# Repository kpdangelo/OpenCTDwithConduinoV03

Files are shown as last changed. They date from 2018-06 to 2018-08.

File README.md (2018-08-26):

# OpenCTDwithConduinoV03

This has drift issues, see https://github.com/kpdangelo/OpenCTD-Conduino-K1.0

This is version 3 of my conduino implementation
The circuit more closely follows the Analog Devices app note, CN-0217, in an attempt to mitigate the drift I was seeing in the Conduino reading with versions 1 and 2.
Namely, the AC coupling capacitors in series with the USB electrodes were taken studied, and a SPDT analog mux was added to swap the electrodes for each measurement in an attempt to see if there was biasing going on of the electrodes.
All fairly inconclusive at this time.

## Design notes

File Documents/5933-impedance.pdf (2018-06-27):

AD5933 Output Impedance

AC coupling at the VOUT output of the AD5933 creates signal attenuation due to the RO/R1/C1 pole and C1/R1 zero. Where RO is the 600Ω output impedance when the AD5933 is configured in output Range 4.

With 1uF and 1.6kΩ C1/R1 combination, the 100 kHz signal is attenuated by approximately 2.8dB.

Changing to the recommended values of 47nF and 25kΩ from the AD5933 datasheet results in a much lower attenuation of approximately 0.2dB.

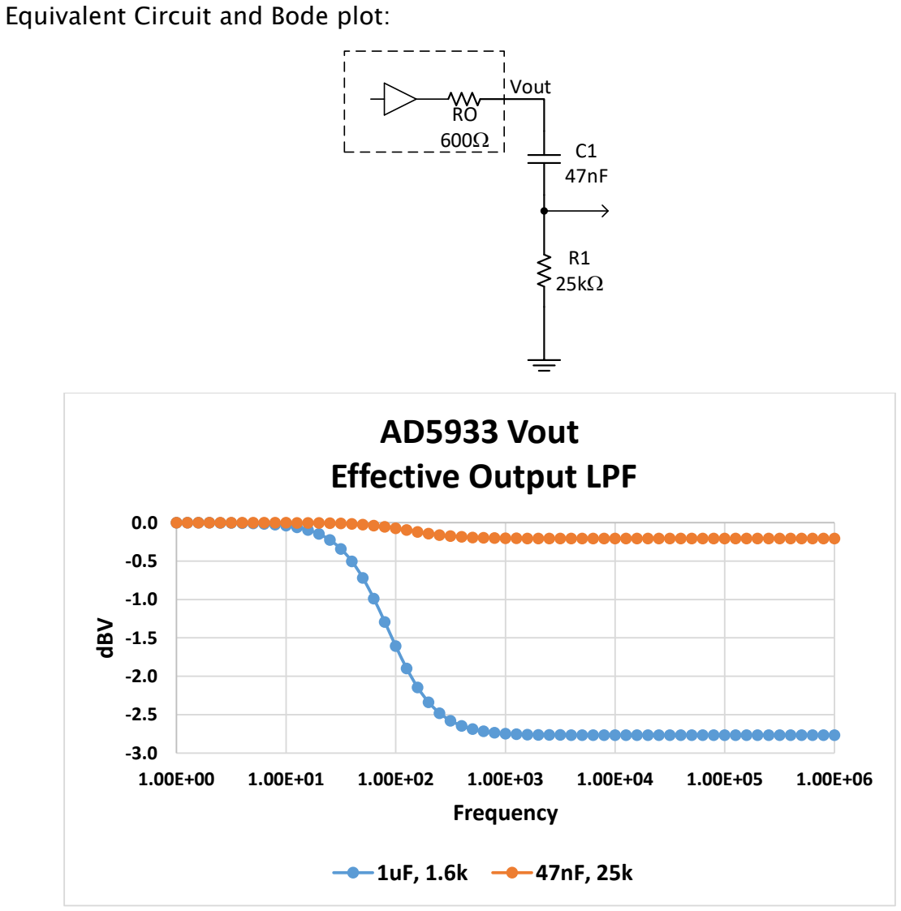
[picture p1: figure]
Equivalent Circuit and Bode plot:; Vout; dBV; Frequency; AD5933 Vout Effective Output LPF

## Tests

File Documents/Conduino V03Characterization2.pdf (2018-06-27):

Conduino V03 Characterization

1. Using a reference 180 ohm resistor

Using an 0603 resistor soldered to the end of a 9” USB cable. The resistor is a Panasonic ERA-3AEB181V, 0.1% 180 Ohm, with a 25 ppm temp-co.

Pretty stable, has 0.08% noise in the reading. Something happened at about 5 ½ hours, maybe the watch-dog timer was triggered. There is a 0.35% transient in the reading there. Notice that the temperature also had a transient at the same time, so something odd happened.

At 10 minute startup, the reading is 0.04% below where it ends up hours later.

Temperature has no measurable effect since the resistor temp-co is so small.

Compared to the USB probe, this looks pretty stable.

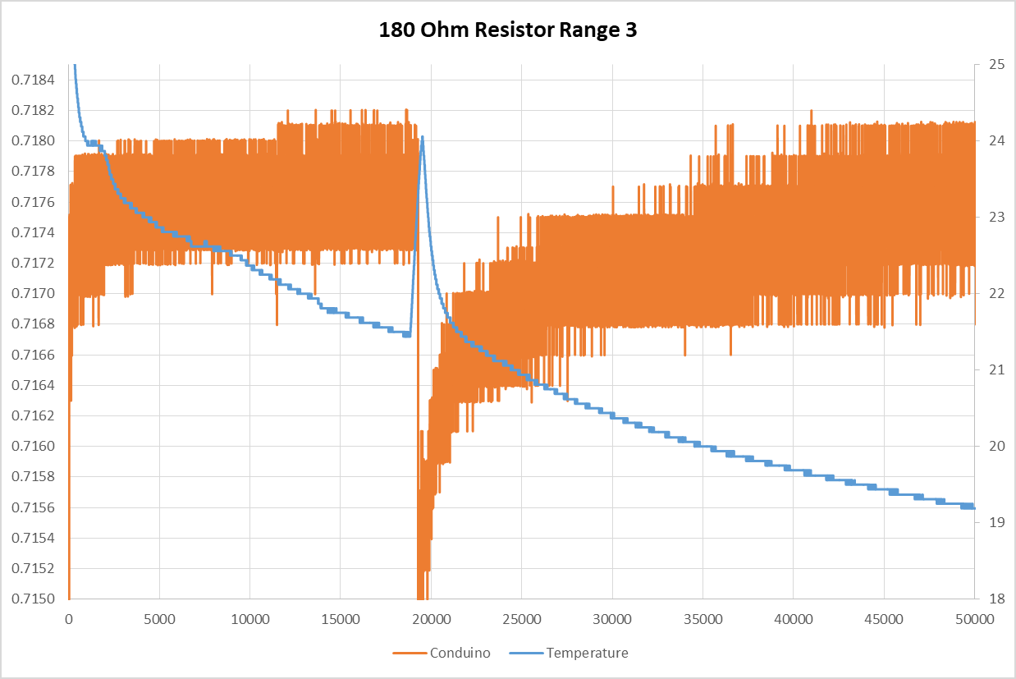
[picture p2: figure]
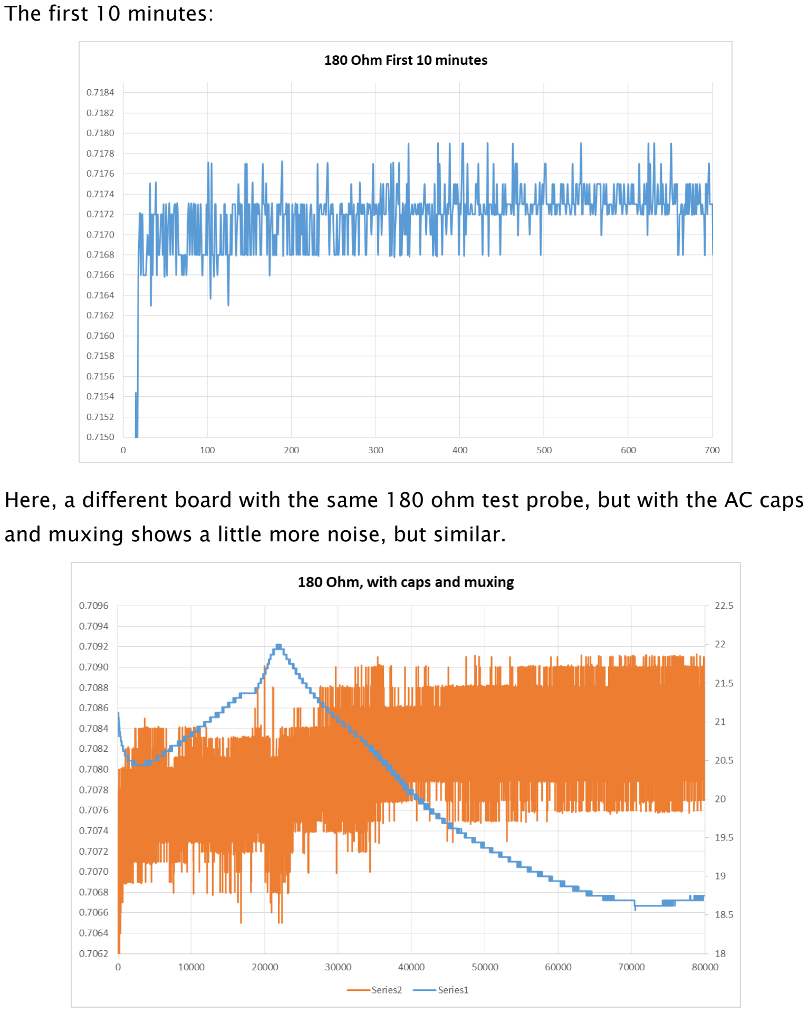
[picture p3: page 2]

The first 10 minutes:

Here, a different board with the same 180 ohm test probe, but with the AC caps and muxing shows a little more noise, but similar.

2. Tests using a USB probe in ~35ppt saline solution with a recirculation pump. The AC caps are C1 and C4 that are in series with the D+ and Delectrodes of the USB probe. The mux is a 2-channel SPDT analog switch. It is used to swap the USB probe electrodes each time a measurement is taken.
AC Caps | Mux | Notes
No | No | So-so tracking, strong startup drift
No | Yes | Similar
Yes | Yes | So-so tracking, strong startup drift
Yes | No | Really bad tracking and startup drift

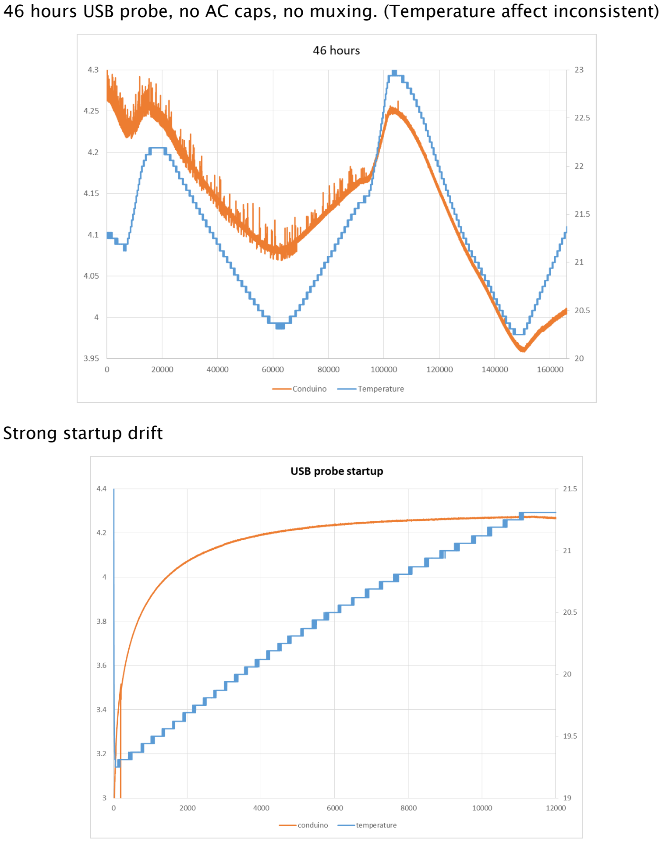
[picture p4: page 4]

46 hours USB probe, no AC caps, no muxing. (Temperature affect inconsistent)

Strong startup drift

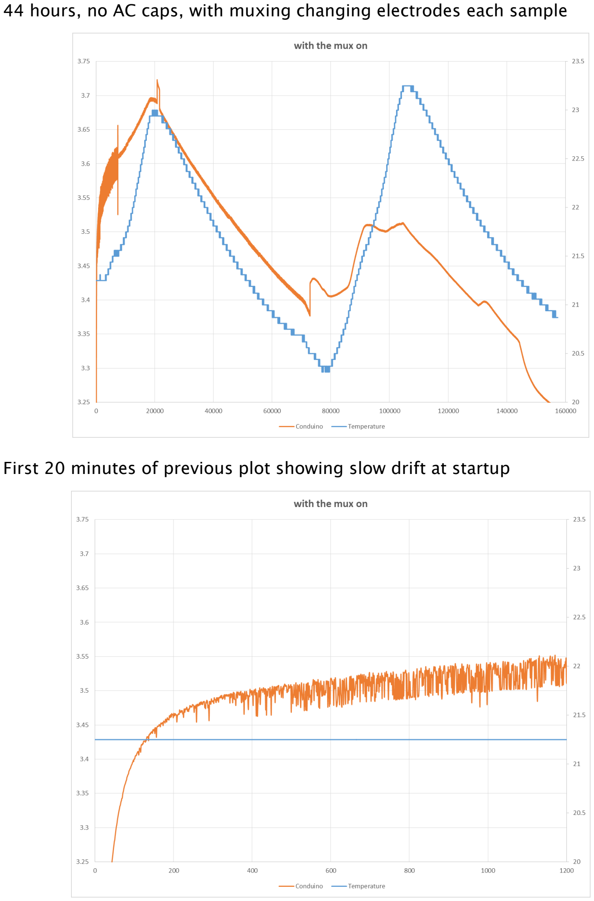
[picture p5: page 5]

44 hours, no AC caps, with muxing changing electrodes each sample

First 20 minutes of previous plot showing slow drift at startup

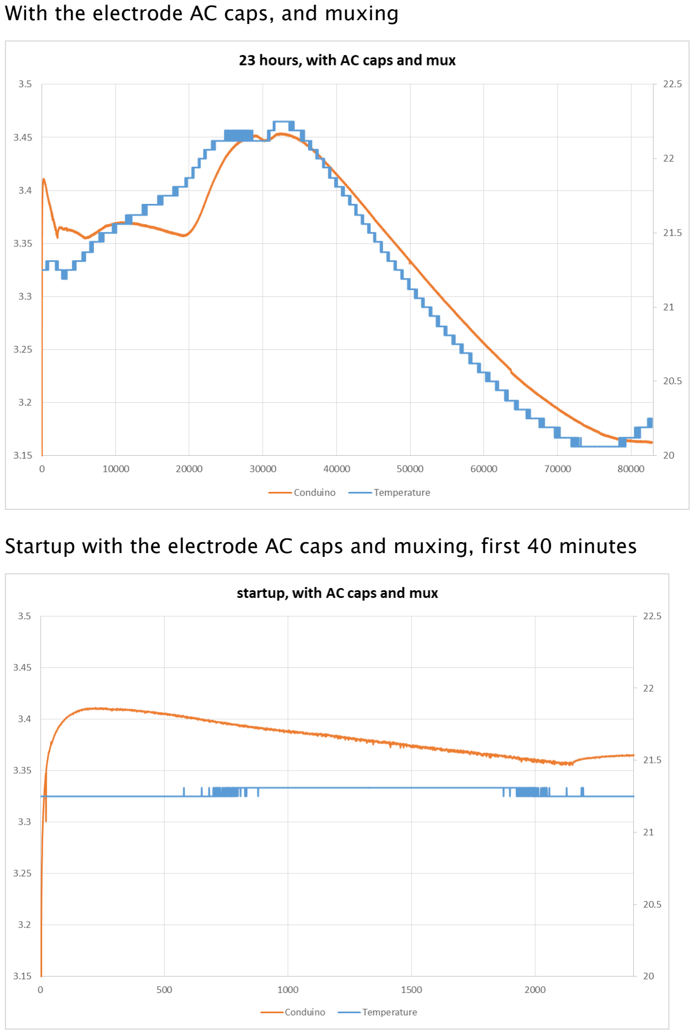
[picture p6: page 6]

With the electrode AC caps, and muxing

Startup with the electrode AC caps and muxing, first 40 minutes

With AC caps but no mux, shows strong drift unrelated to temperature

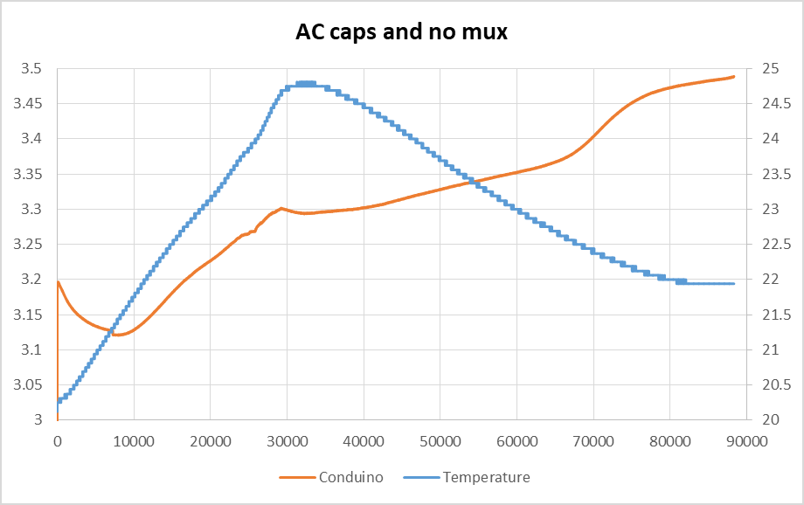
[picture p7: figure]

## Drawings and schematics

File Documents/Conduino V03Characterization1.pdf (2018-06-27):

Conduino V03 Characterization

V03 uses a low noise LDO (LP5907) to create a local 3.3v supply for the Conduino analog circuitry. Resistor dividers are used to bias the amplifiers (per Analog Devices app note CN-0217). Series AC capacitors are shorted. LDO is cycled on and off for each measurement once a second.

V03 also has a low input offset (65uV) amplifier (ADA8606) with plenty of bandwidth (10 MHz).

Result of long soak, measurement following temperature (decent?):

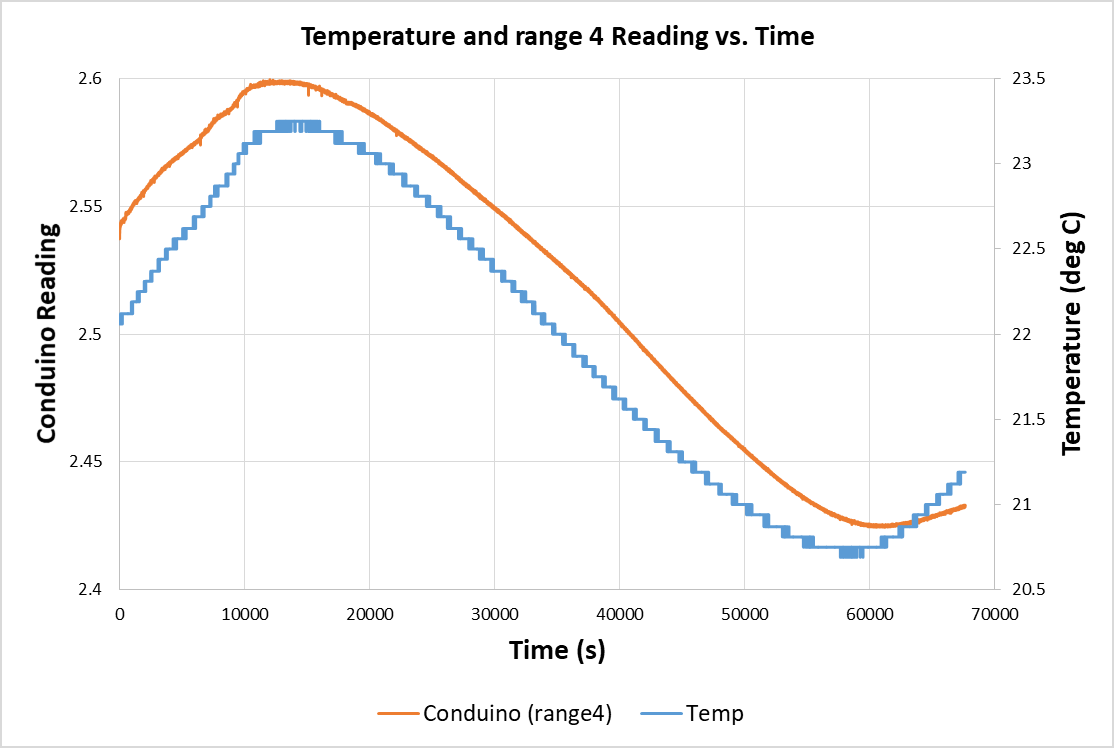
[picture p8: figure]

At the end of this run, the USB probes broke off.

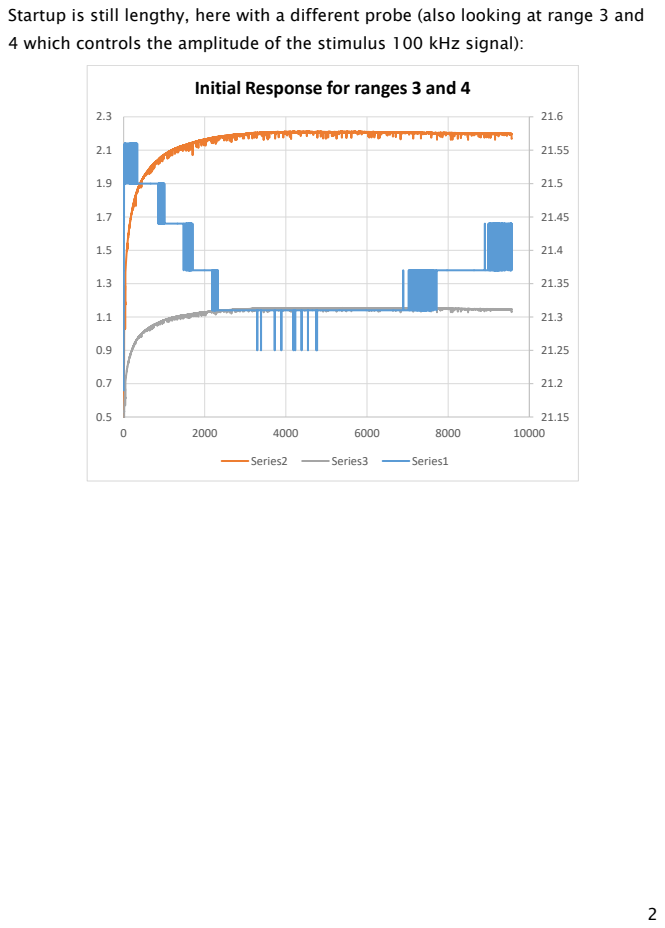
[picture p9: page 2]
Series2; Series3; Series1

Startup is still lengthy, here with a different probe (also looking at range 3 and
4 which controls the amplitude of the stimulus 100 kHz signal):

Initial Response for ranges 3 and 4

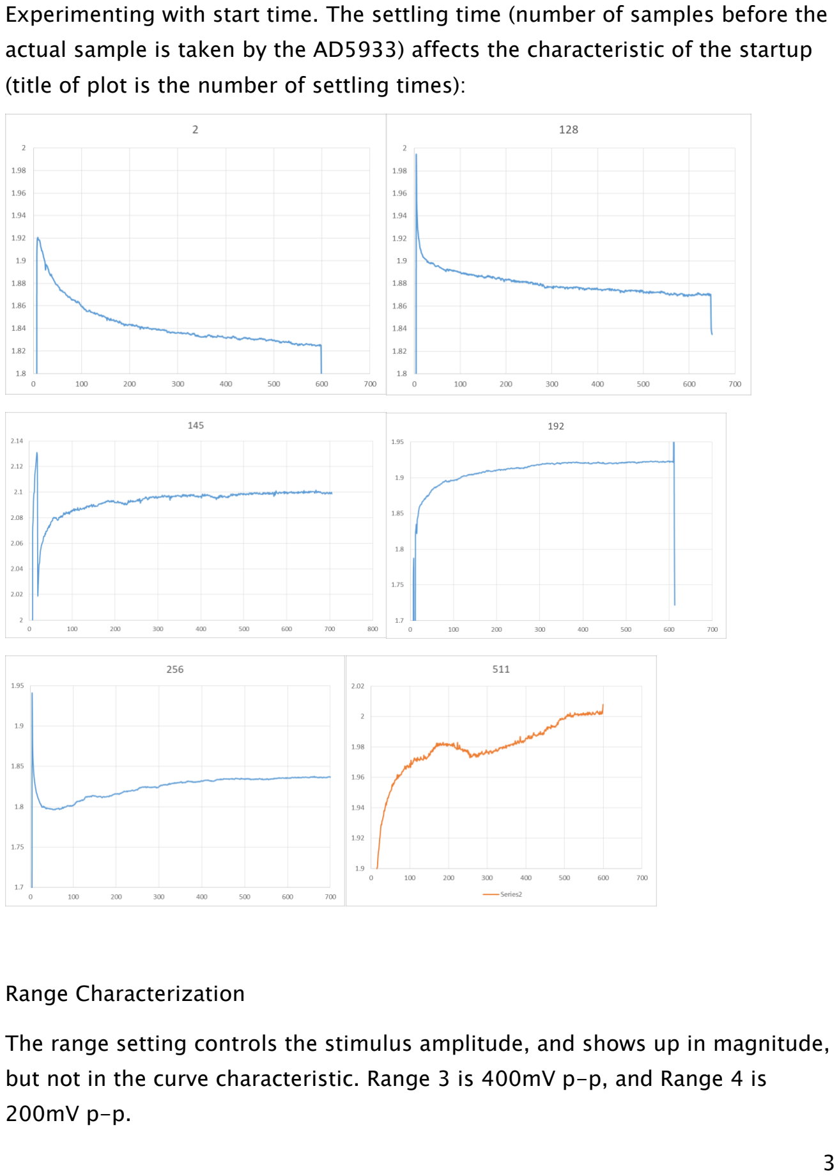
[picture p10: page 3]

Experimenting with start time. The settling time (number of samples before the actual sample is taken by the AD5933) affects the characteristic of the startup (title of plot is the number of settling times):

Range Characterization

The range setting controls the stimulus amplitude, and shows up in magnitude, but not in the curve characteristic. Range 3 is 400mV p-p, and Range 4 is 200mV p-p.

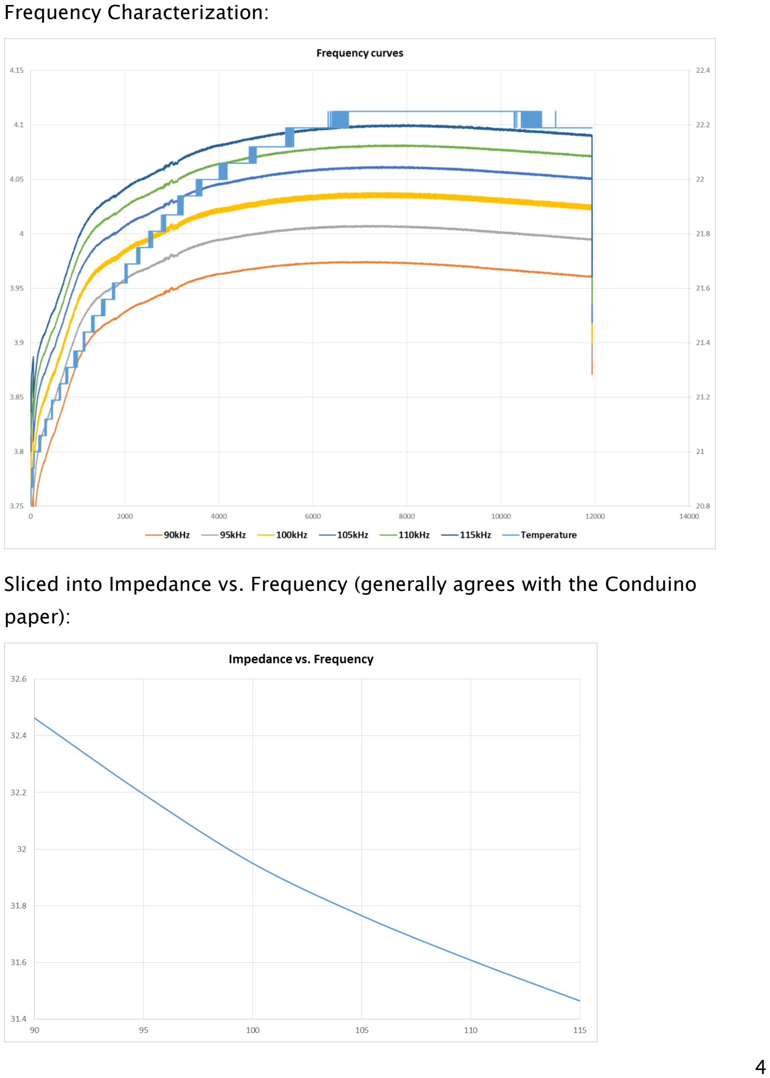
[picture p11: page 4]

Frequency Characterization:

Sliced into Impedance vs. Frequency (generally agrees with the Conduino paper):

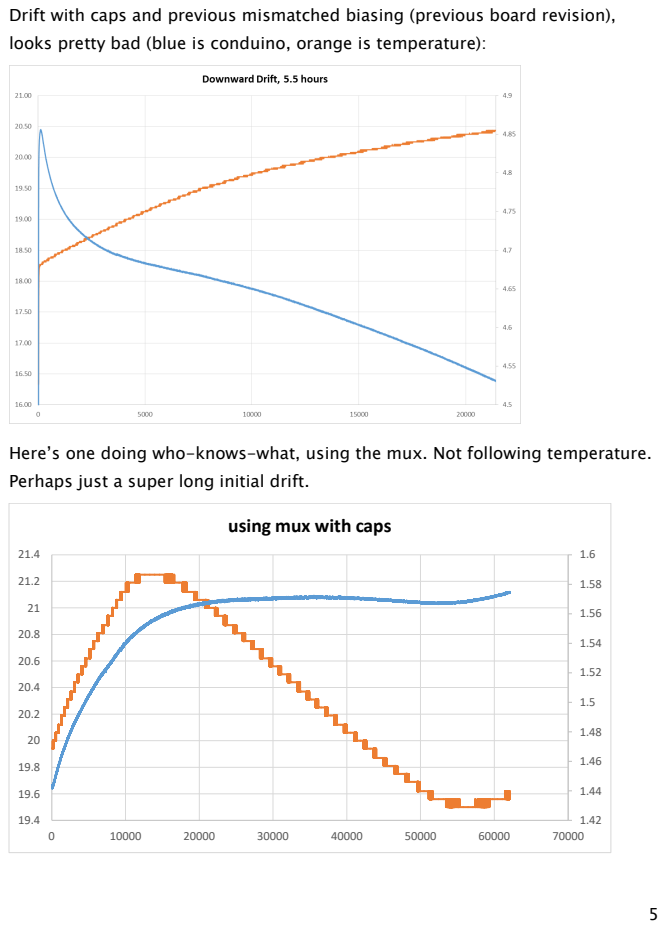
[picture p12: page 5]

Drift with caps and previous mismatched biasing (previous board revision),
looks pretty bad (blue is conduino, orange is temperature):

Here’s one doing who-knows-what, using the mux. Not following temperature.
Perhaps just a super long initial drift.

using mux with caps

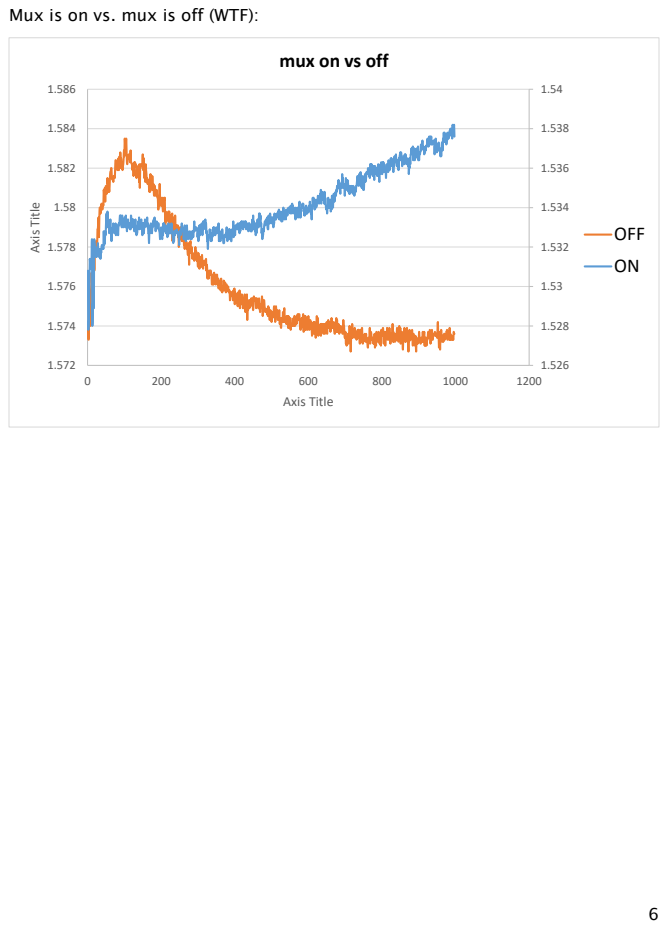
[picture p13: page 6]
Axis Title; OFF

Mux is on vs. mux is off (WTF):

mux on vs off

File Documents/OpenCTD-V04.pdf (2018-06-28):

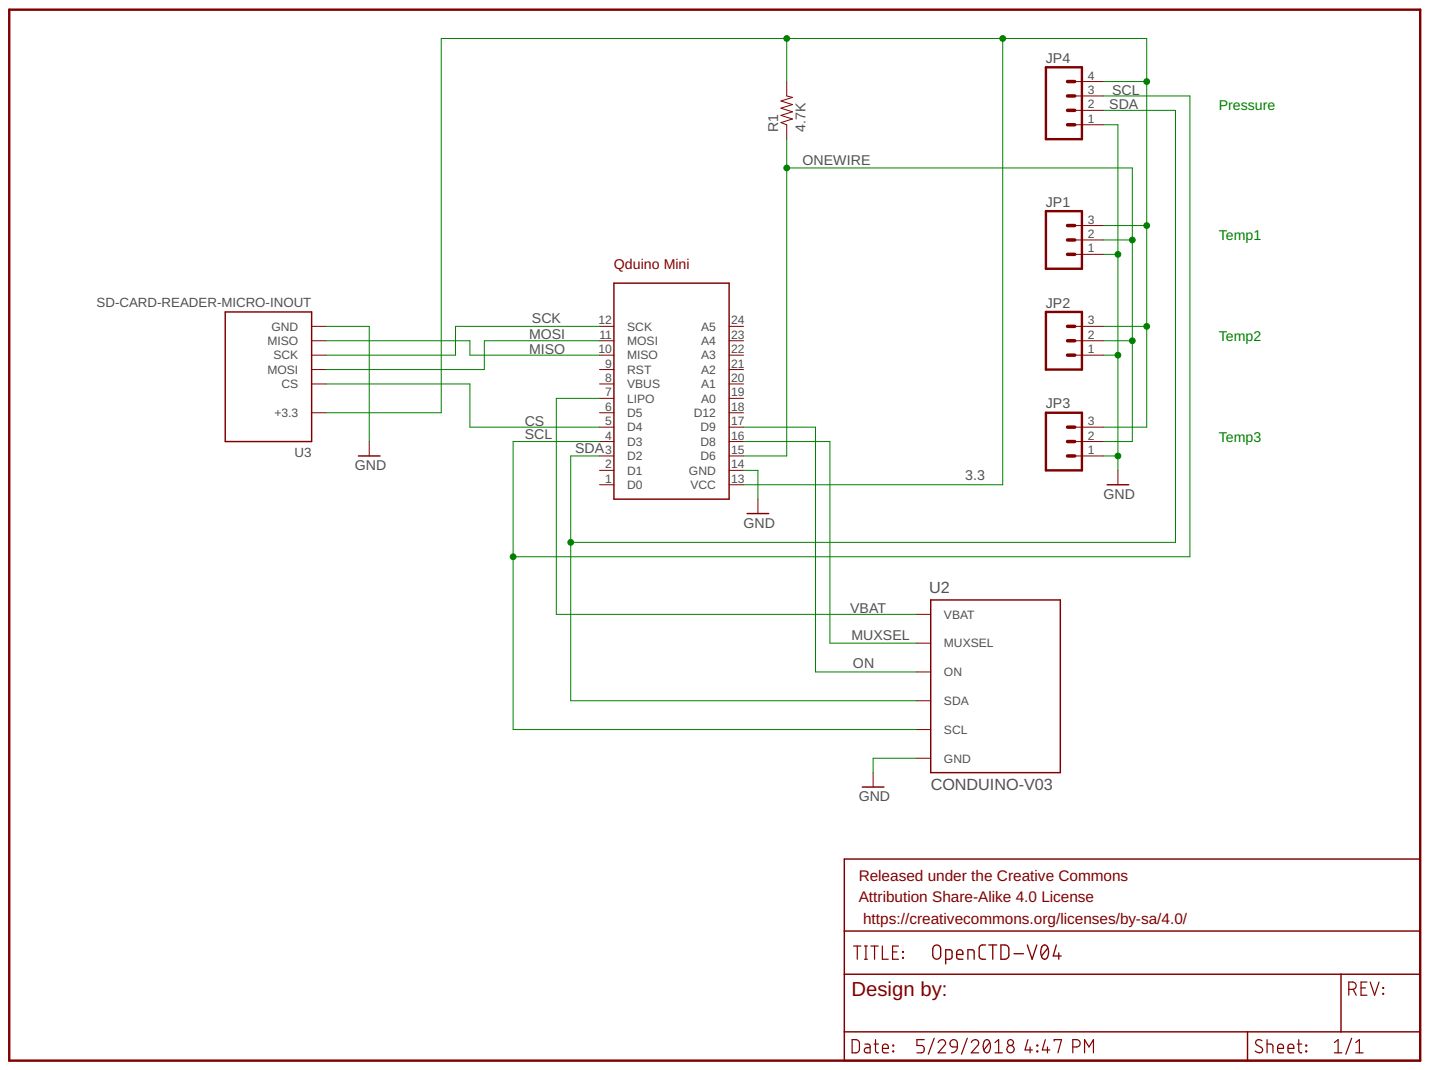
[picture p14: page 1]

2 SDA

SD-CARD-READER-MICRO-INOUT

SCL SDA ONMUXSEL VBAT

Released under the Creative Commons Attribution Share-Alike 4.0 License

https://creativecommons.org/licenses/by-sa/4.0/

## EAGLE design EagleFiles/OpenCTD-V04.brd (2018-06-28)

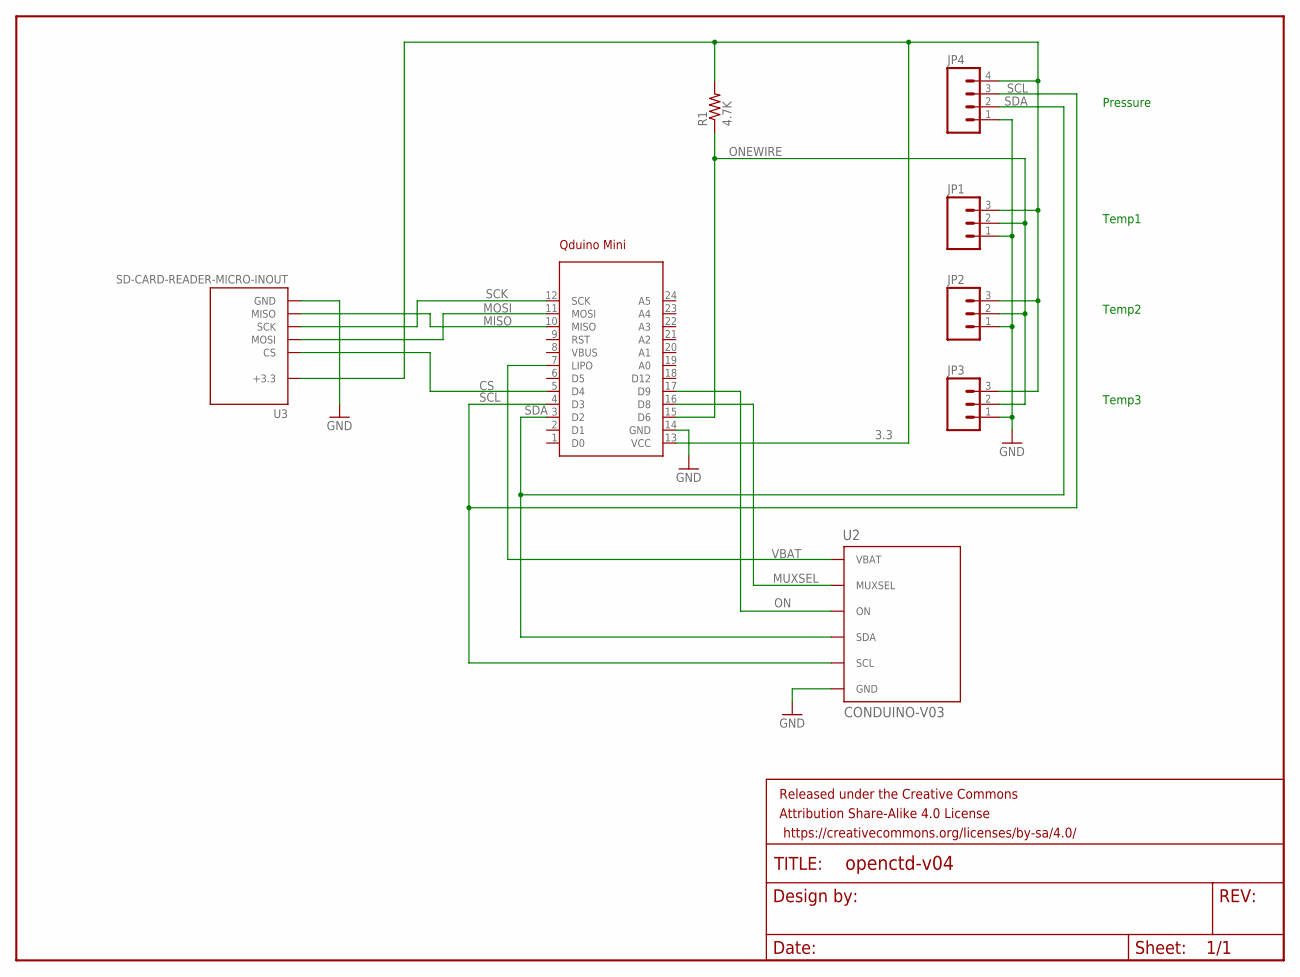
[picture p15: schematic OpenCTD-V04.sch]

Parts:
FRAME1: FRAME-LETTER; CREATIVE_COMMONS
JP1, JP2, JP3: M031X03_NO_SILK; 1X03_NO_SILK
JP4: M041X04_NO_SILK; 1X04_NO_SILK
R1: 4.7K; AXIAL-0.4
U1: QDUINO_MINI
U2: CONDUINO-V03; CONDUINO_V03
U3: SD-CARD-READER-MICRO-INOUT; SD-CARD-READER-105162

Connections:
3.3: JP1.3, JP2.3, JP3.3, JP4.4, R1.P$2 (2), U1.13 (VCC), U3.P$4 (+3.3)
CS: U1.5 (D4), U3.P$2 (CS)
GND: JP1.1, JP2.1, JP3.1, JP4.1, U1.14 (GND), U2.5 (GND), U3.G1 (GND), U3.G2 (GND), U3.G3 (GND), U3.G4 (GND), U3.P$6 (GND)
MISO: U1.10 (MISO), U3.P$7 (MISO)
MOSI: U1.11 (MOSI), U3.P$3 (MOSI)
MUXSEL: U1.16 (D8), U2.4 (MUXSEL)
ON: U1.17 (D9), U2.3 (ON)
ONEWIRE: JP1.2, JP2.2, JP3.2, R1.P$1 (1), U1.15 (D6)
SCK: U1.12 (SCK), U3.P$5 (SCK)
SCL: JP4.3, U1.4 (D3), U2.1 (SCL)
SDA: JP4.2, U1.3 (D2), U2.2 (SDA)
VBAT: U1.7 (LIPO), U2.6 (VBAT)

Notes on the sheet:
Pressure
Temp1
Temp2
Temp3

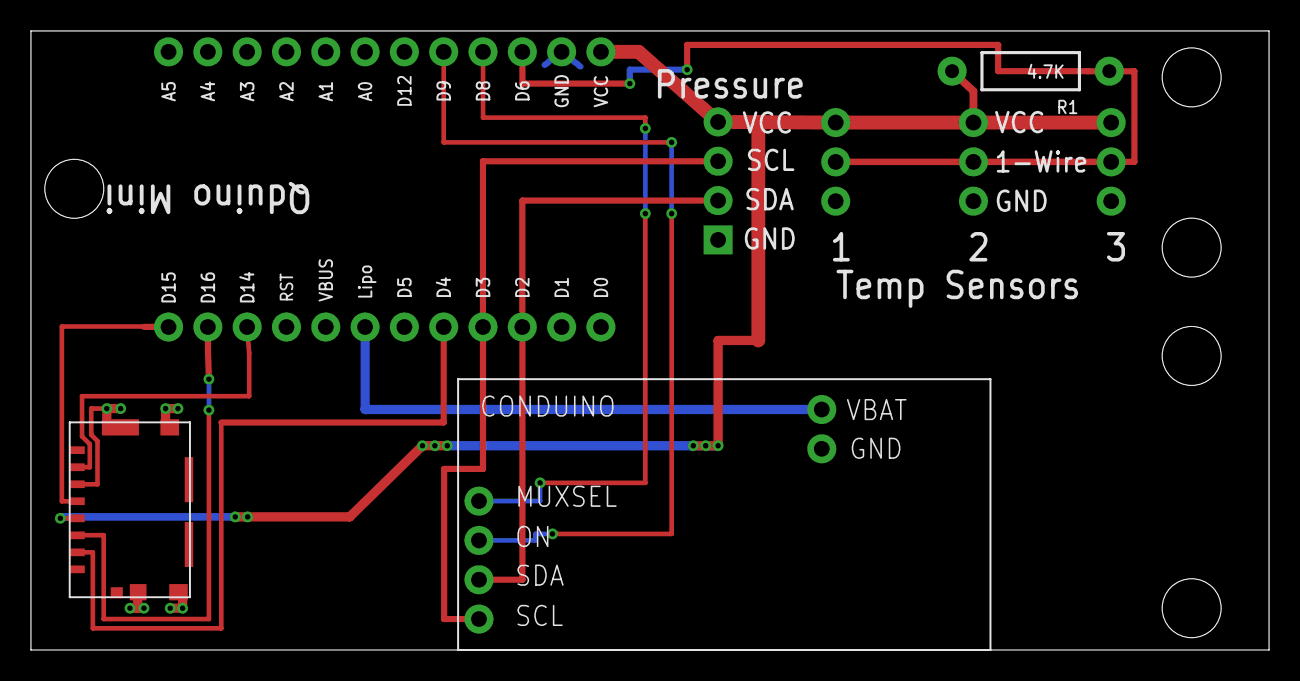
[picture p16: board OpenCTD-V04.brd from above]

Board: 2 copper layers, 80.0 x 40.0 mm, 9 parts (0 on the bottom side), 12 nets.

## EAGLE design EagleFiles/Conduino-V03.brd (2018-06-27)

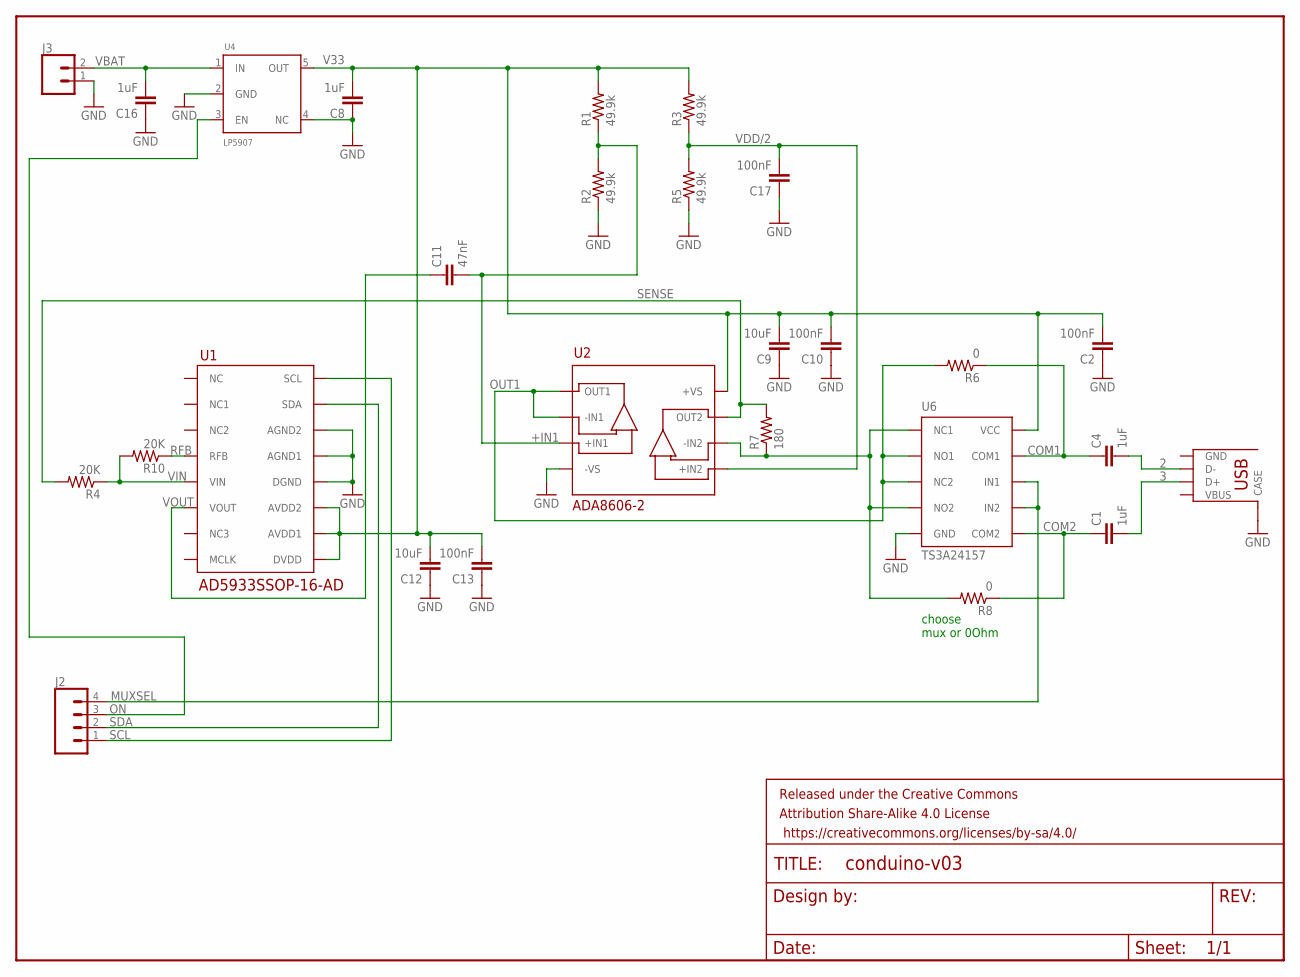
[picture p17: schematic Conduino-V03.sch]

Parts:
C1, C4, C8, C16: 1uF; 0603-CAP
C2, C10, C13, C17: 100nF; 0603-CAP
C9, C12: 10uF; 0603-CAP
C11: 47nF; 0603-CAP
FRAME1: FRAME-LETTER; CREATIVE_COMMONS
J1: USBA-SIDE
J2: CONN_041X04_NO_SILK; 1X04_NO_SILK
J3: CONN_021X02_NO_SILK; 1X02_NO_SILK
R1, R2, R3, R5: 49.9k; 0603-RES
R4, R10: 20K; 0603-RES
R6, R8: 0; 0603-RES
R7: 180; 0603-RES
U1: AD5933SSOP-16-AD; SSOP-16-AD
U2: ADA8606-2; SOIC_N
U4: LP5907; SOT23-5L
U6: TS3A24157; VSSOP-10

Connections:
2: C4.2, J1.P$2 (D-)
3: C1.2, J1.P$3 (D+)
+IN1: C11.2, R1.1, R2.2, U2.P$3 (+IN1)
-IN2: R7.1, R8.2, U2.P$6 (-IN2), U6.P$1 (NC1), U6.P$4 (NO2)
COM1: C4.1, R6.1, U6.P$9 (COM1)
COM2: C1.1, R8.1, U6.P$6 (COM2)
GND: C2.1, C8.1, C9.1, C10.1, C12.1, C13.1, C16.1, C17.1, J1.P$5 (CASE), J1.P$6 (CASE), J3.1, R2.1, R5.1, U1.P$12 (DGND), U1.P$13 (AGND1), U1.P$14 (AGND2), U2.P$4 (-VS), U4.2 (GND), U4.4 (NC), U6.P$5 (GND)
MUXSEL: J2.4, U6.P$7 (IN2), U6.P$8 (IN1)
ON: J2.3, U4.3 (EN)
OUT1: R6.2, U2.P$1 (OUT1), U2.P$2 (-IN1), U6.P$2 (NO1), U6.P$3 (NC2)
RFB: R10.1, U1.P$4 (RFB)
SCL: J2.1, U1.P$16 (SCL)
SDA: J2.2, U1.P$15 (SDA)
SENSE: R4.2, R7.2, U2.P$7 (OUT2)
V33: C2.2, C8.2, C9.2, C10.2, C12.2, C13.2, R1.2, R3.2, U1.P$9 (DVDD), U1.P$10 (AVDD1), U1.P$11 (AVDD2), U2.P$8 (+VS), U4.5 (OUT), U6.P$10 (VCC)
VBAT: C16.2, J3.2, U4.1 (IN)
VDD/2: C17.2, R3.1, R5.2, U2.P$5 (+IN2)
VIN: R4.1, R10.2, U1.P$5 (VIN)
VOUT: C11.1, U1.P$6 (VOUT)

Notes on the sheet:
choose mux or 0Ohm

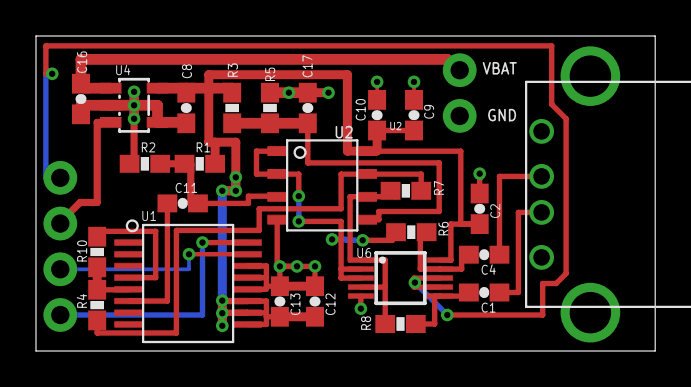
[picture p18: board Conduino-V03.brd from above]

Board: 2 copper layers, 34.4 x 17.5 mm, 28 parts (0 on the bottom side), 19 nets.

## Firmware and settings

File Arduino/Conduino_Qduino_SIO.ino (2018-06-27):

///////////////////////////////////////////////////////////////////////////////////////////////////////////////
/*
   Conduino_Qduino_SIO

   This sketch controls the Conduino and reads one temperature probe

   This sketch is adapted from the open CTD from Oceanography for Everyone
   also found here are links to getting the Qduino libraries for Arduino
   http://www.oceanographyforeveryone.com/
   https://github.com/OceanographyforEveryone/OpenCTD

   Sensors are
   Dallas 1-wire temperature sensors
   Conduino conductivity sensor which uses the AD5933 Network Analyzer

   Marco Carminati, Paolo Luzzatto-Fegiz,
   Conduino: Affordable and high-resolution multichannel water conductivity sensor using micro USB connectors,
   In Sensors and Actuators B: Chemical, Volume 251, 2017, Pages 1034-1041, ISSN 0925-4005,
   https://doi.org/10.1016/j.snb.2017.05.184.

   output format on SD card:
   TimeStamp(seconds) Temperature (deg C) Conduino Reading

   D8 controls mux to swap electrodes
   D9 is the conduino's voltage regulator ON/OFF where HIGH = ON

   Kevin D'Angelo
   6/25/18
*/
/////////////////////////////////////////////////////////////////////////////////////////////////////////////////
#include <Wire.h>
#include "Qduino.h"
qduino q;
#include <avr/wdt.h>      // watch dog timer
///////////////////////////////////////////////////////////////////////////////////////////////
//  Sample Interval
//  watch dog timer is continuously reset while waiting for sample interval.
////////////////////////////////////////////////////////////////////////////////////////////////
#define SampleInterval 1000      // 1000 ms
///////////////////////////////////////////////////////////////////////////////////////////////////////////////
// Temperature related
///////////////////////////////////////////////////////////////////////////////////////////////////////////////
//OneWire is used to get data from both temperature and conductivity sensors
#include <OneWire.h>  //

//DallasTemperature is used to query the temeprature sensors
#include <DallasTemperature.h>   //

// For the SD card reader.
#include <SPI.h>
#include <SD.h>

// Declare global variables.
float tempA;

OneWire oneWire(6);        // Define the OneWire port for temperature.
DallasTemperature sensors(&oneWire);  // Define DallasTemperature input based on OneWire.

/////////////////////////////////////////////////////////////////////////////////
//    CONDUINO RELATED
///////////////////////////////////////////////////////////////////////////////
// The user must calibrate the AD5933 system for a known impedance range to determine the gain factor

#define AD5933_ADDR 0x0D

double ConduinoReading;
double Conductivity;
double magnitude;
double phase;
double impedance;
double gain = 3.086 * pow(10, -6); //calibrated with 98.5Ohm resistor on 6/3/18

const float CLOCK_SPEED = 16.776 * pow(10, 6); // AD5933 has internal clock of 16.776 MHz

const int CONTROL_REGISTER[2] =                    { 0x80, 0x81       }; // see mapping below
const int START_FREQUENCY_REGISTER[3] =            { 0x82, 0x83, 0x84 }; // 24 bits for start frequency
const int FREQ_INCREMENT_REGISTER[3] =             { 0x85, 0x86, 0x87 }; // 24 bits for frequency increment
const int NUM_INCREMENTS_REGISTER[2] =             { 0x88, 0x89       }; //  9 bits for # of increments
const int NUM_SETTLING_CYCLES_REGISTER[2] =        { 0x8A, 0x8B       }; //  9 bits + 1 modifier for # of settling times
const int STATUS_REGISTER[1] =                     { 0x8F             }; // see mapping below
const int TEMPERATURE_DATA_REGISTER[2] =           { 0x92, 0x93       }; // 16-bit, twos complement format
const int REAL_DATA_REGISTER[2] =                  { 0x94, 0x95       }; // 16-bit, twos complement format
const int IMAG_DATA_REGISTER[2] =                  { 0x96, 0x97       }; // 16-bit, twos complement format

// control register map (D15 to D12)
const int DEFAULT_VALUE =                 B0000; // initial setting
const int INITIALIZE =                    B0001; // excite the unknown impedance initially
const int START_SWEEP =                   B0010; // begin the frequency sweep
const int INCREMENT =                     B0011; // step to the next frequency point
const int REPEAT =                        B0100; // repeat the current frequency point measurement
const int MEASURE_TEMP =                  B1001; // initiates a temperature reading
const int POWER_DOWN =                    B1010; // VOUT and VIN are connected internally to ground
const int STANDBY =                       B1011; // VOUT and VIN are connected internally to ground

const int BLOCK_WRITE = B1010000;
const int BLOCK_READ =  B1010001;
const int ADDRESS_PTR = 0xB0;// B1011000;

const int validTemperatureMeasurement =  1;
const int validImpedanceData =           2;
const int frequencySweepComplete =       4;

int temperatureData;

//functions declarations
int checkStatus();
boolean measureTemperature();
byte frequencyCode(float, int);
boolean setStartFrequency(float);
boolean setFrequencyIncrement(float);
boolean setNumberOfIncrements(int);
boolean setNumberOfSettlingTimes(int);
void measureImpedance();
void configureAD5933(int, float, float, int);
int getByte(int);
boolean setByte(int, int);
boolean setControlRegister(int);

boolean setControlRegister2();

int reading = 0;
byte rxByte;
int number;
char FirstChar[1];
char SecondChar[1];

int e = 0;
int y;
int ch;
int u;
int real;
int imag ;

long timeStamp;
long time1;
int i;
/////////////////////////////////////////////////////////////////////////////////
//    setup()
///////////////////////////////////////////////////////////////////////////////
void setup() {
  Wire.begin();
  Serial.begin(9600);
  wdt_enable(WDTO_2S);      // 2 second watch dog timer reset interval
  q.setup();

  pinMode(8, OUTPUT);   // use for scope timing measurements
  pinMode(9, OUTPUT);   // Conduino ON/OFF (goes to regulator EN)

  if (!SD.begin(4)) {
    q.setRGB(RED);    // SD card bad, turn on the red light
    wdt_reset();      // pet the dog
    delay(1000);
    return;
  }
  else {          // SD card is good, turn on the green light for 1 second
    q.setRGB(GREEN);
    wdt_reset();      // pet the dog
    delay(1000);
    q.ledOff();
  }

  wdt_reset();      // pet the dog

  sensors.begin();    // Initialize the temperature sensors

  digitalWrite (8, LOW);    // set mux control to low
  digitalWrite (9, LOW);    // conduino disable

  time1 = millis();     // initialize time stamp
}
/////////////////////////////////////////////////////////////////////////////////
//    loop()
///////////////////////////////////////////////////////////////////////////////
void loop() {

  timeStamp += millis() - time1;
  time1 = millis();

  // Read temperature sensors.
  sensors.requestTemperatures();      // takes 622 ms
  tempA = sensors.getTempCByIndex(0);

  digitalWrite (9, HIGH);    // conduino enable
  delay (1);                  // settling time for regulator 3.3v output
  measureImpedance();       // get measurement from Conduino
  digitalWrite (9, LOW);    // conduino disable
  digitalWrite (8, !digitalRead(8));    // toggle mux control state

  File dataFile = SD.open("datalog.txt", FILE_WRITE);   // takes ~4ms
  if (dataFile) {
    dataFile.print(timeStamp / 1000.0); dataFile.print(" ");
    dataFile.print(tempA); dataFile.print(" ");
    dataFile.print(ConduinoReading, 4); dataFile.print(" ");
    dataFile.println("");
    dataFile.close();
  }

  //    Write to serial monitor or not Comment/Uncomment
  //Serial.print(timeStamp / 1000.0); Serial.print(" ");
  //Serial.print (tempA); Serial.print(" ");
  //Serial.print (magnitude); Serial.print(" ");
  // Serial.print (ConduinoReading, 4); Serial.print(" ");  // for calibration
  //Serial.println("");

  while (millis() - time1 < SampleInterval) { // wait for Sample Interval
    wdt_reset();              // reset the watchdog timer in case SampleInterval > 2000
  }
}
////////////////////////////////////////////////////////////////////////
//  Conduino Related Subroutines
////////////////////////////////////////////////////////////////////////
// message sequence:
// to set the memory address:
// 1. slave address
// 2. pointer command
// 3. register address to point to

// to write data (address already set):
// 1. slave address
// 2. block write
// 3. number bytes write
// 4. byte 0, byte 1, byte 2, etc.

// to read data (address is already set):
// 1. slave address with read bit high
// 2. register data is returned

// to read a block of data (address is already set):
// 1. slave address
// 2. block read
// 3. number of bytes
// 4. slave address (read bit high)
// 5. byte 0, byte 1, byte 2, etc.

// control register map (D10 to D9)
// ranges = {2.0 V p-p, 200 mV p-p, 400 mV p-p, 1.0 V p-p}

// control register map (D11, D8 to D0)
// D11 = no operation
// D8 = PGA gain (0 = x5, 1 = x1) // amplifies the response signal into the ADC
// D7 = reserved, set to 0
// D6 = reserved, set to 0
// D5 = reserved, set to 0
// D4 = reset // interrupts a frequency sweep
// D3 = external system clock, set to 1; internal system clock, set to 0
// D2 = reserved, set to 0
// D1 = reserved, set to 0
// D0 = reserved, set to 0

// number of increments register
// 0x88: D15 to D9 -- don't care
// 0x89: D8 -- number of increments bit 1
// 0x89: D7 to D0 -- number of increments bits 2 through 9; 9-bit integer number stored in binary format

// number of settling times
// 0x8A: D15 to D11 -- don't care
// 0x8A: D10 to D9 -- 2-bit decode
//        0 0 = default
//        0 1 = # of cycles x 2
//        1 0 = reserved
//        1 1 = # of cycles x 4
// 0x8A: D8 -- MSB number of settling times
// 0x8B: D7 to D0 -- number of settling times; 9-bit integer number stored in binary format

const int OUTPUT_VOLTAGE[4] = {
  B00, B01, B10, B11
};

/////////////////////////////////////////////////////////////////////////////////
//    Measure Impedance
///////////////////////////////////////////////////////////////////////////////
void measureImpedance() {

  real = 0;
  imag = 0;
  e = 0;
  ControlReset();
  configureAD5933(145, // Conduino network analyzer, number of settling times
                  95000, // start frequency (Hz)
                  1, // frequency increment (Hz)
                  0); // number of increments

  // read and display the 5933 registers
  //  Serial.print("0x80:"); Serial.print(ReadReg(0x80), HEX); Serial.print (" ");
  //  Serial.print("0x81:"); Serial.print(ReadReg(0x81), HEX); Serial.print (" ");
  //  Serial.print("0x82:"); Serial.print(ReadReg(0x82)); Serial.print (" ");
  //  Serial.print("0x83:"); Serial.print(ReadReg(0x83)); Serial.print (" ");
  //  Serial.print("0x84:"); Serial.print(ReadReg(0x84)); Serial.print (" ");
  //  Serial.print("0x85:"); Serial.print(ReadReg(0x85)); Serial.print (" ");
  //  Serial.print("0x86:"); Serial.print(ReadReg(0x86)); Serial.print (" ");
  //  Serial.print("0x87:"); Serial.print(ReadReg(0x87)); Serial.print (" ");
  //  Serial.println("");

  //0.Inizialize bit D11,D10,D9,D8
  setControlRegister2(3);   // range=3, 400mv signal

  // 1. place AD5933 in standby mode
  setControlRegister(STANDBY);
  // 2. initialize with start frequency
  setControlRegister(INITIALIZE);
  // add a delay here
  delay(10);

  // 3. start frequency sweep
  setControlRegister(START_SWEEP);

  while (checkStatus() < validImpedanceData) {    // wait for DFT to complete
    wdt_reset();
  }
  real = getByte(REAL_DATA_REGISTER[0]) << 8;
  real |= getByte(REAL_DATA_REGISTER[1]);

  imag = getByte(IMAG_DATA_REGISTER[0]) << 8;
  imag |= getByte(IMAG_DATA_REGISTER[1]);

  magnitude = sqrt(pow(double(real), 2) + pow(double(imag), 2));
  phase = atan(double(imag) / double(real)) * 360 / (2 * 3.14) + 47;
  impedance = 1 / (gain * magnitude);
  ConduinoReading = (129 / impedance);

  setControlRegister(INCREMENT);

  //  measureTemperature();           // keep track of AD5933 internal temperature
  // 8. power-down mode
  setControlRegister(POWER_DOWN);
}
/////////////////////////////////////////////////////////////////////////////////
//    check status register, used in polling
///////////////////////////////////////////////////////////////////////////////
int checkStatus() {
  return (getByte(STATUS_REGISTER[0]) & 7);
}
/////////////////////////////////////////////////////////
//  read registers
//////////////////////////////////////////////////////
int ReadReg(int addr) {
  return (getByte(addr));
}
/////////////////////////////////////////////////////////////////////////////////
//    Measure internal temperature of network analyzer chip
///////////////////////////////////////////////////////////////////////////////
boolean measureTemperature() {
  setControlRegister(MEASURE_TEMP);
  delay(10); // wait for 10 ms
  if (checkStatus() & 1 == validTemperatureMeasurement) {

    // temperature is available
    temperatureData = getByte(TEMPERATURE_DATA_REGISTER[0]) << 8;
    temperatureData |= getByte(TEMPERATURE_DATA_REGISTER[1]);
    temperatureData &= 0x3FFF; // remove first two bits

    if (temperatureData & 0x2000 == 1) { // negative temperature
      temperatureData -= 0x4000;
    }
    temperatureData /= 32;
    setControlRegister(POWER_DOWN);
    return true;
  }
  else {
    return false;
  }
}
/////////////////////////////////////////////////////////////////////////////////
//    start frequency and frequency increment formula
///////////////////////////////////////////////////////////////////////////////
byte frequencyCode(float freqInHz, int byteNum) {
  long value = long((freqInHz / (CLOCK_SPEED / 4)) * pow(2, 27));

  //  Serial.print(value); Serial.print(" ");

  byte code[3];

  code[0] = (value & 0xFF0000) >> 0x10;
  code[1] = (value & 0x00FF00) >> 0x08;
  code[2] = (value & 0x0000FF);

  //  Serial.print(code[0]); Serial.print(" ");
  //  Serial.print(code[1]); Serial.print(" ");
  //  Serial.print(code[2]); Serial.print(" ");
  //  Serial.println("");

  return code[byteNum];
}
/////////////////////////////////////////////////////////////////////////////////
//    start frequency and frequency increment formula:
///////////////////////////////////////////////////////////////////////////////
boolean setStartFrequency(float freqInHz) {
  boolean statusValue;
  //Serial.print("StartFrequency:"); Serial.print(freqInHz); Serial.print(" ");

  for (int n = 0; n < 3; n++) {
    statusValue = setByte(START_FREQUENCY_REGISTER[n], frequencyCode(freqInHz, n));
  }

  return statusValue;
}
/////////////////////////////////////////////////////////////////////////////////
//    start frequency and frequency increment formula:
///////////////////////////////////////////////////////////////////////////////
boolean setFrequencyIncrement(float freqInHz) {
  boolean statusValue;
  //Serial.print("FreqIncrement:"); Serial.print(freqInHz); Serial.print(" ");

  for (int n = 0; n < 3; n++) {
    statusValue = setByte(FREQ_INCREMENT_REGISTER[n], frequencyCode(freqInHz, n));
  }
  return statusValue;
}
/////////////////////////////////////////////////////////////////////////////////
//    start frequency and frequency increment formula:
///////////////////////////////////////////////////////////////////////////////
boolean setNumberOfIncrements(int n) {

  boolean i2cStatus;

  int numIncrements = min(n, 511);
  //Serial.print("No_Incr:"); Serial.print(n); Serial.print(" ");

  i2cStatus = setByte(NUM_INCREMENTS_REGISTER[0], numIncrements >> 8);
  i2cStatus = setByte(NUM_INCREMENTS_REGISTER[1], numIncrements & 255);

  return i2cStatus;
}
/////////////////////////////////////////////////////////////////////////////////
//    start frequency and frequency increment formula:
///////////////////////////////////////////////////////////////////////////////
boolean setNumberOfSettlingTimes(int n) {

  int decode;
  int numSettlingTimes = min(n, 2047);

  if (n > 1023) {
    decode = 3;
    numSettlingTimes /= 4;
  }
  else if (n > 511) {
    decode = 1;
    numSettlingTimes /= 2;
  }
  else {
    decode = 0;
    numSettlingTimes = n;
  }

  boolean i2cStatus;
  //Serial.print("Settling:"); Serial.print(n); Serial.print(" ");

  i2cStatus = setByte(NUM_SETTLING_CYCLES_REGISTER[0], (numSettlingTimes >> 8) + (decode << 1));
  i2cStatus = setByte(NUM_SETTLING_CYCLES_REGISTER[1], numSettlingTimes & 255);

  return i2cStatus;
}
/////////////////////////////////////////////////////////////////////////////////
//    Configure network analyzer register settings
///////////////////////////////////////////////////////////////////////////////
void configureAD5933(int settlingTimes, float startFreq, float freqIncr, int numIncr) {
  setNumberOfSettlingTimes(settlingTimes);
  setStartFrequency(startFreq);
  setFrequencyIncrement(freqIncr);
  setNumberOfIncrements(numIncr);
}
///////////////////////////////////////////////////////////////////////////////
// How to write or read a byte:
// 1. master device asserts a start condition on SDA
// 2. master sends the 7-bit slave address followed by the write bit (low)
// 3. addressed slave device asserts an acknowledge on SDA
// 4. The master send a register address or pointer command code (1011 0000)
// 5. the slave asserts an acknowledge on SDA
// 6. the master sends a data byte or register address to where the pointer is to point
// 7. the slave asserts an acknowledge on SDA
// 8. the master asserts a stop condition on SDA to end the transaction
/////////////////////////////////////////////////////////////////////////////////
//    data I/O
///////////////////////////////////////////////////////////////////////////////
int getByte(int address) {
  int rxByte;
  Wire.beginTransmission(AD5933_ADDR);
  Wire.write(ADDRESS_PTR);
  Wire.write(address);
  int i2cStatus = Wire.endTransmission();

  Wire.requestFrom(AD5933_ADDR, 1);

  if (1 <= Wire.available()) {
    rxByte = Wire.read();
  }
  else {
    rxByte = -1;
  }
  return rxByte;
}
/////////////////////////////////////////////////////////////////////////////////
//    data I/O
///////////////////////////////////////////////////////////////////////////////
boolean setByte(int address, int value) {

  Wire.beginTransmission(AD5933_ADDR);
  Wire.write(address);
  Wire.write(value);
  int i2cStatus = Wire.endTransmission();

  if (i2cStatus)
    return false;
  else
    return true;
}
/////////////////////////////////////////////////////////////////////////////////
//    control register
///////////////////////////////////////////////////////////////////////////////
boolean setControlRegister(int code) {

  int rxByte = getByte(CONTROL_REGISTER[0]);

  rxByte &= 0x0F; // clear upper four bits
  rxByte |= code << 4; // set to 1011

  boolean s = setByte(CONTROL_REGISTER[0], rxByte);

  delay(1);

  return s;
}
////////////////////////////////////////////////////////////////////////////
//  reset bit of control register
///////////////////////////////////////////////////////////////////////
void ControlReset() {
  setByte(CONTROL_REGISTER[1], 0x10);

}
/////////////////////////////////////////////////////////////////////////////////
//    control register, here you can set the magnitude of the stimulus signal
///////////////////////////////////////////////////////////////////////////////
boolean setControlRegister2(int range) {

  int rxByte = getByte(CONTROL_REGISTER[0]);

  rxByte &= 0xF0; // clear lower four bits
  switch (range) {
    case 2:
      rxByte |= B00000111; // set to 11 PGA gain=x1, Range2: 1v
      break;
    case 3:
      rxByte |= B00000101;  // set to 10 PGA gain=x1, range3: 400mv
      break;
    case 4:
      rxByte |= B00000011; // set to 01 PGA gain=x1, Range4: 200mv,
      break;
  }
  //  rxByte |= B00000011; // set to 01 PGA gain=x1, Range4: 200mv, this setting from UCSB (180 measured), Range4
  //  rxByte |= B00000111; // set to 11 PGA gain=x1, Range2: 1v
  //  rxByte |= B00000001;  // set to 00 PGA gain=x1; Range1: 2v
  //  rxByte |= B00000101;  // set to 10 PGA gain=x1, range3: 400mv

  boolean s = setByte(CONTROL_REGISTER[0], rxByte);
  delay(10);
  return s;
}

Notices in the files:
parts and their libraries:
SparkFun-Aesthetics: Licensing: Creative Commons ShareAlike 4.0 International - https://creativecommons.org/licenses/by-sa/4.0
